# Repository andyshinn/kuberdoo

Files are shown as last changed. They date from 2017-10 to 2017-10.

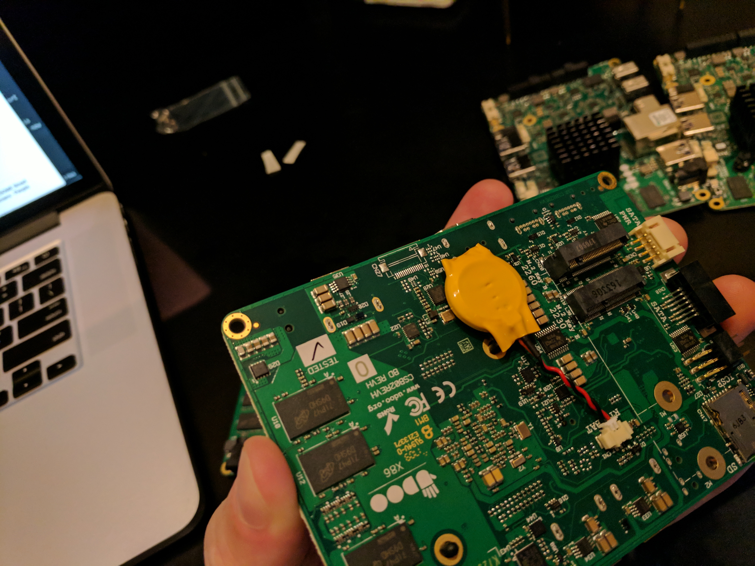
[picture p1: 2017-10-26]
photos/IMG_20171011_182746.jpg

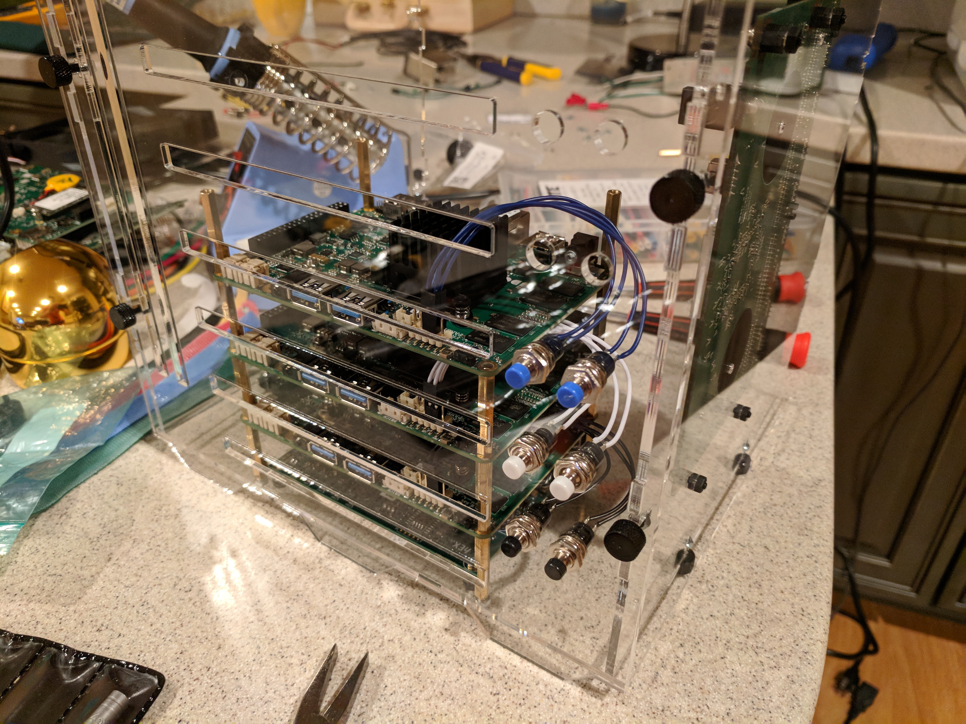
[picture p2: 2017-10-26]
photos/IMG_20171024_211047.jpg

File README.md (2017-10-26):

# About

The Kuberdoo is a not-so-cheap take on a Raspberry Pi cluster. I had originally tested building a small desktop cluster based on the Raspberry Pi but ended up with more compatibility issues than I hoped for. My search for a comparable x86 board started...

There are a couple x86 boards out there. The closest to the UDDO in price and features was the Up Board. Others, such as the Jaguarboard, were lacking in specifications or were not clear if they were even available for purchase (Kickstarter or other). I purchased one UDOO to confirm I could do some things (such as running Docker containers without tweaks and native PXE boot capabilities).

I wanted to build a case around all the components. A friend prototyped an acrylic case that could be laser cut. I immediately started playing with Onshape to take the idea to completion. After learning how to sketch and build the panels, I took the drawings to Pololu for supplying and cutting the acrylic.

## Components

Let's go through some of the main build components and how they came to be. Some of these could be swapped out for different sizes or models. I'll try and point out some of the places where I would have done differently.

### Boards

The main board is the UDOO X86 Advanced.

I did some research on boards. I had originally wanted to go with a Raspberry Pi design. But like most of the other ARM platforms I found in the Pi price range, I just ran into too many limitations for what I wanted to do (the biggest one being lack of proper PXE support). The ARM compatibilities around containers was also frustrating enough that I wanted to go x86_64. Though, I imagine in another year or two, we'll be able to have proper LAN boot options and more transparent multi-architecture support in technologies like Docker.

The UDOO X86 Advanced was the board I settled on. Some of the stuff I wanted to work with (such as Juju) require 4GB of RAM. The Advanced version of the board fit the bill. I imagine two ways to cut costs would be to either go with the Advanced Plus model (which has 32GB eMMC storage built-in) or go with the Basic model and use a cheaper SD card as storage and get only 2GB RAM (in my notes near the bottom I talk about SD storage and why I chose to use a M.2 SSD instead).

### Case

The case is built from laser cut 3mm thick acrylic panels. The CAD is actually public at https://cad.onshape.com/documents/991c4a5831e2f997a4a71842/w/bb91f76a25a96fa561acf156/e/013c2a1a40829f74b89b5690. Anyone can open it up and check out the parts and assembly!

The case was the most fun exercise. I had never used any CAD style tooling before so there was a definite learning curve. But I had some help from a friend who had experience. I stumbled upon Onshape and it felt like a very polished tool. I am actually surprised at how much it is able to do in the browser.

I did not have any calipers (I do now!) for measuring parts at the time. Most of my part and mounting dimensions were from ruler and/or visual only. This led to issues that popped up during assembly:

* The switch mounting holes didn't all line up. Turns out, the mounting holes on the switch PCB are not a perfect rectangle. Oops! I should be able to get the holes aligned better now that I have a pair of calipers.
* The PSU mounting is too far forward. The bottom of the PSU is resting against the front mounting nuts. Not a huge deal but I'll move the PSU back about 5mm so it clears the nuts.
* The notches in the top of the rear panel are not lined up perfectly with the notches in the top panel (off by about 1mm). I was able to use some wire cutters to try the notch in the top panel so it would fit. You can actually see this in the Onshape assembly, I just missed it during my review.
* The bottom panel bears most of the weight yet it only attaches to the sides. This could probably be designed a little better to attach at the front and back as well. Though, being able to screw the top panel into the standoffs help alleviate any pressure by the boards. Not as bad as it sounds (you can't really see it bowing) but it could be better.
* The edges of the case have some flex to them. The notches could have probably been spread out more evenly instead of right next to the bolt holes.
* The front air vents are off by 1.6mm compounding for each vent as I forgot to account for the thickness of the board. Oops again!

The case I built was version `V3`. I went through and tweaked a bunch of constraints for the some of the issues above. If I ever build another case (or if you do, please let me know) I will make a version `V4`.

### Power Supply

The power supply unit (PSU) is a Mean Well RS-100-12. I would later learn that this is an older model and has been replaced by the LRS-100-12. The LRS-100-12 is smaller, has a better efficiency rating (should run cooler), and slightly cheaper. For new builds I'd recommend just using the LRS-100-12.

I looked at dual voltage power supplies (since I was initially thinking I would run a 5v switch and that the fan would be 5v as well). But it turned out to be much bulkier to get the wattage needed at 12 and 5 volts. I also finally found a 12v based switch and realized that most computer fans are actually 12v.

### Networking

The networking components consist of a Netgear GS108 switch, MikroTik hEX router, and some Monoprice SlimRun ethernet cables. The hEX has mechanical drawings available but I couldn't find any for the GS108. Fortunately, it had mounting holes on the board and I was (mostly) able to figure out the correct hole to hole dimensions.

The GS108 was the only switch ii found that was powered by 12 volts (most others were 5 or 9). The hEX has a very wide range input voltage so no worries there. But both the GS108 and hEX are a bit pricey for what they are doing. I think the hEX could be swapped out for the hEX lite and the GS108 for another 12v switch if I searched longer. I am also not fond of the GS108 DC power jack on the back. Had it been on the same side of the ethernet ports I would have been able to move the switch forward a bit more to create some cable space.

The hEX acts not only as a NAT gateway for the internal network but also as a VPN server. To get into the network I create a L2TP VPN connection in my macOS network settings. Once connected, I get access as if I was directly connected to the switch.

I go into the router and VPN configuration specifics later in the installation instructions.

### Fan, Ethernert, C14

The fan is a Antec TwoCool 140mm. The ethernet jack and C13 receptacle were just whatever I found available on Amazon. I'm sure any comparable parts would work as long as the dimensions were tweaked to fit them.

I got the fan in a dual speed model because I wasn't sure how much airflow I needed. So far, the low speed on the fan works well and seems to be keeping everything cool. I haven't measured temperatures yet. But just touching the PSU and heatsinks on the boards feels much cooler than being in the open air.

### Other

There are some other various parts that I already had on hand but I'll try to list them out in case they are needed:

* M3 x 5mm nylon standoffs (brass or metal would be fine as well).
* M3 washers (for spacing the boards off the base panel)
* 18 AWG wire (for building the wiring harness from the PSU to the DC pigtails)
* Various tools (philips screw driver, wire cutters, wire tap crimpers)
* Soldering iron and solder
* Spade terminals for 18 AWG wire (for easy connecting to C14 receptacle. though, you could also just solder the wires on).
* Eye hole terminals for 18 AWG wire to PSU outputs and inputs (though, you could probably just screw the bare wires in if you wanted).
* Shrink tubing in various sizes.
* Double sided foam tape.

## Instructions

Now that you have all the parts, let's get building!

### Router Configuration

Before we install the router we need to do some pre-configuration so we can connect to it.

1. Connect up your computer to the second ethernet port and make sure it is configured for DHCP.
1. Power up the hEX with the included power adapter.
1. SSH or telnet to 192.168.88.1.
1. Copy and paste the configuration from https://github.com/andyshinn/kuberdoo/blob/master/config/default_vpn.rsc (this should get the NAT, firewall, VPN, and basics set up).

After loading the configuration, connect port 1 up to your home network, power cycle the hEX, and verify that you can connect to it (you will need to consult your home router to find out what address the MikroTik was given). For example, my home network is 10.0.1.0/24 and the MikroTik got an address of 10.0.1.58. I am able to connect to the device via SSH at 10.0.1.58 with user `admin` and password `kub3rd00`. There is also a web interface at http://10.0.1.58/ if you prefer to configure the device that way.

Now that we have verified the device can be remotely connected to, it is ready to be installed into the case. You can leave the router powered up because we'll use the TFTP server configured on it to bootstrap the first UDOO board next.

### UDOO Preparation

In addition to the router, we need to prep the UDOO boards so that they properly boot from PXE and failover to hard drive when no PXE server is available. We also need to install Ubuntu on one of the boards so that we have a node to bootstrap from.

1. Install the M.2 SSDs onto all the boards. The UDOO X86 should have come with a small bag of M.2 mounting hardware.
1. Use a small piece of double sided foam tape to hold down the CMOS battery.
1. Connect up a UDOO to monitor via HDMI or mini DisplayPort, keyboard, and a 12 volt DC power adapter. You can use the one that comes with the Netgear GS108 switch. But don't use the adapter that comes with the MikroTik hEX as it is 24 volts!
1. Start repeatedly pressing the <kbd>ESC</kbd> key on the keyboard while applying power to the UDOO board.
1. Enter the SCU once at the setup screen.
1. Navigate to _Power_ and set the _Power Fail Resume Type_ to _Always OFF_ (we don't want to boards automatically powering on).
1. Navigate to _Boot_ menu.
1. Set _Boot Type_ to _Legacy_ (UEFI doesn't failover to hard disk properly when PXE fails).
1. Enable _PXE boot to LAN_.
1. Navigate to _Exit_ and choose _Exit Saving Changes_.
1. Keep pressing the ESC key as the device reboots again.
1. Navigate to the _Boot_ menu again and there should be a new _Legacy_ menu.
1. Under _Legacy_ submenu navigate to _Boot Type Order_.
1. Highlight _Hard Disk Drive_ and use the <kbd>-</kbd> key to move it under _Other_ (so that PXE will boot before the SSD).
1. Navigate to _Exit_ and choose _Exit Saving Changes_.

Repeat these steps for all the boards. It is difficult to hook up HDMI and keyboard to the boards while they are in the case so this is why we do it now. We want the boards to boot and install headless.

Choose one of the boards to be the head node. This is the board we'll use to install Ubuntu onto and will run Ubuntu MAAS or other PXE server to bootstrap the other boards. With this board:

1. Connect the board up to your monitor and keyboard again.
1. Connect this board to one of the ethernet ports on the MikroTik hEX.
1. Power on the board and it should PXE boot into https://netboot.xyz/ from the TFTP server we previously set up on the hEX.
1. Navigate the menus to install Ubuntu 16.04 or other flavor of Linux (if you plan to use something other than MAAS).
1. Follow through the installation and verify you can SSH to the node afterwards.

Once we can remotely connect to this node it is safe to go in the case. We know that we can connect to it without needing monitor and keyboard. It may be helpful to number the boards at this point. I put a number 1 on my head node CMOS battery and labeled the others boards 2 through 6.

### Wiring Harness

I started by mocking up the boards on the bottom panel and the PSU on the side panel. This helped give an idea of how long the DC plug pigtails needed to be for the wiring harness. I ended up making two, one harness for the 6 boards and one for the fan, switch, and router. The harnesses are the pigtails soldered to 18 AWG wire leads that plug into the positive and negative terminals on the PSU.

### Mounting Switch

### Mounting Router

### Head Node MAAS

```
sudo apt install maas
sudo maas createadmin
```

## Notes

### Storage

The UDOO X86 supports SD card, SATA, and M.2 type SSD. It also has a model that has a built-in 32GB eMMC option.

I tested using a SD card (Samsung 32GB EVO Select U1) and it was too slow for my liking. Definitely the cheaper of the options available (only $13 on Amazon at the time). If speed isn't your primary concern then this would be an option to keep cost down. It would be worth looking at the Samsung 64GB EVO Select U3 or other U3 SD cards as they should be faster than the U1.

I picked up the lowest cost 64GB M.2 SSD I could get on Amazon. It turned out to be magnitudes faster than the SD card. In comparison, it took 20+ minutes to install Ubuntu onto the Samsung 32GB EVO and only about 5 minutes onto the M.S SSD.

You might look at the 1.8 inch SATA SSD available if space and cabling is less of a concern. With these you'd likely get more performance and space per dollar. I won't need more than 64GB per node and didn't want to deal with the extra parts and cabling.

I figured if the SD card was this slow then a USB key wouldn't be much faster so I didn't test this option. But a faster USB drive could be an option if space and cabling isn't a concern.

### Network

One of my goals was to have an isolated network for protocols like PXE, DHCP, and DNS. This should allow use of the cluster for testing that might conflict with the parent network. I also needed something that would act as a VPN server as it would be my way into the network.

I had looked at some smaller home routers and boards to run pfSense. But none of them fit well (not enough ports, too big, more expensive than home routers). I then stumbled upon Mikrotik (which I had known about for many years). The [hEX](https://mikrotik.com/product/RB750Gr3) (and [hEX lite](https://mikrotik.com/product/RB750r2)) were pretty much a perfect fit. I was able to prototype everything the router needed to do in VirtualBox thanks to the Mikrotik x86 distribution.

The next model up (RB2011iL-IN) had 8 ports but not all were gigabit. I think if there were an 8 port version of the hEX or hEX lite at $99 that would have been the better buy rather than a hEX and dumb switch. Even the bare RouterBOARD with more than 1 port ([the RB450](https://mikrotik.com/product/RB450)) costs more than the hEX.

Another thought was to use the [hAP](https://mikrotik.com/product/RB951Ui-2nD) and do wireless client to the parent network. This would remove the need for a wired cable uplink. Though, you'd need to change the wireless client settings anytime it moved to a new wireless network.

### Other

Some other thoughts on other physical cluster stuff I'd love to replicate on the desktop:

* Bonding and port failover. Mikrotik handles this. But we'd need boards that had multiple interfaces (UP squared might be a good candidate for this).
* VLANs and routing between them. Mikrotik already supports this. Would t least need a switch that could also handle VLANs and tagging / trunking.
* IPMI / OOB management. The onboard Arduino has the ability to power on/off the main board. I wonder if it could act as a simple IPMI device?
* HDMI / USB case ports for each board. It should be possible to widen the case and make room for some HDMI and USB passthrough cables for each board. This would make it easier to service (changing BIOS options, debugging broken boot, etc.)

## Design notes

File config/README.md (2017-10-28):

# Config Files

## embed.ipxe

The `embed.ipxe` file is used to build the iPXE `undionly.kpxe` binary with the `embed.ipxe` embedded inside. This PXE booter will chainload to `tftp://192.168.88.1/preseed.ipxe`. This makes it easier for us to make edits to the iPXE script without having to rebuild the iPXE binary. See http://ipxe.org/embed for information on building the binary with the embedded script.

## preseed.cfg

This is the main Ubuntu preseed file. It automates the installation of Ubuntu for us so we don't need a keyboard or monitor. This gets passed to the `url` parameter as a kernel command line option at boot. See the `preseed.ipxe` script for the command line that gets passed.

## preseed.ipxe

This is the chainloaded iPXE script. We use this to pull down a remote Ubuntu installer image and boot using our `preseed.cfg` file. The installation procdes automatically and shuts down the node when done (so we can disable the TFTP options before we next power on).

## preseed.kpxe

This is the `undionly.kpxe` file with our embedded `embed.ipxe` script. It was generated using instructions at http://ipxe.org/embed and then renamed from `undionly.kpxe` to `preseed.kpxe`.

## ros_default.rsc

This is the default configuration of the MikroTik hEX before any of our edits. It is just here for reference.

## ros_kuberdoo.rsc

This is the MikroTik hEX configuration with our edits. It can be applied on top of the default MikroTik configuration. You will likely want to change the DHCP lease MAC addresses of the boards and the global password at top (which is used for VPN and admin functions).

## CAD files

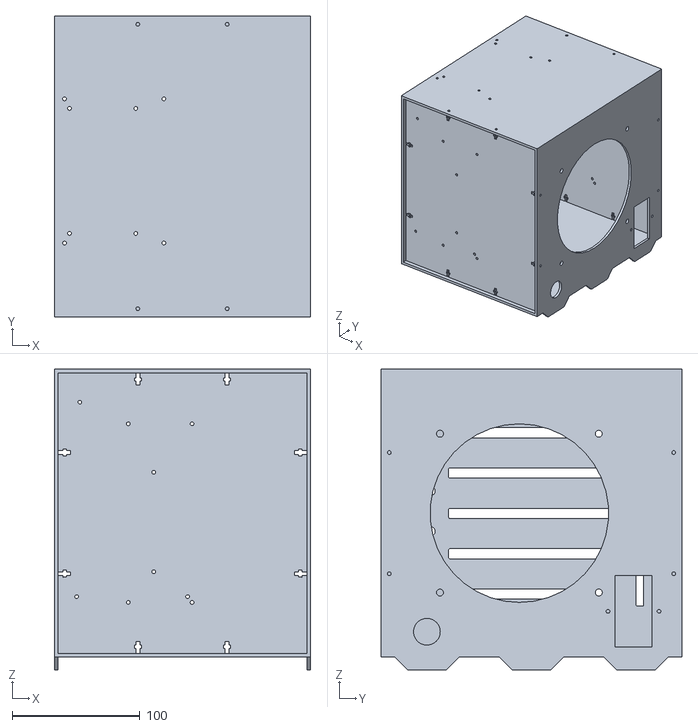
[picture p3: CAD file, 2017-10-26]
drawings/kuberdoo-assembled.stl
201.0 x 236.0 x 236.0

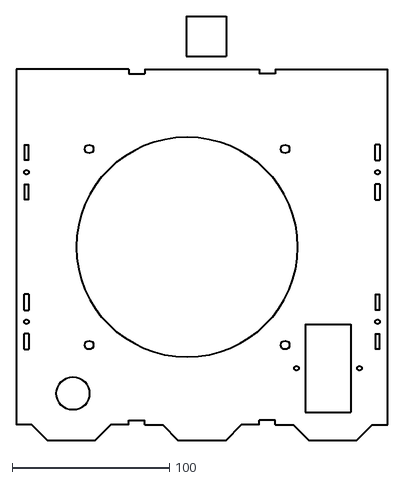
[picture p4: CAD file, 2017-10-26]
drawings/v3/kuberdoo-back-panel-v3.dxf
236.0 x 269.5

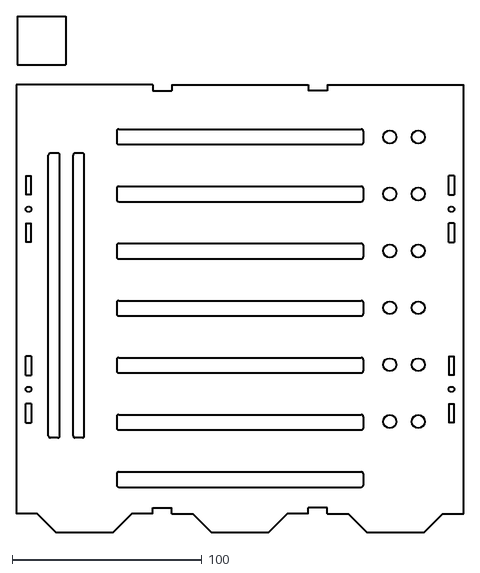
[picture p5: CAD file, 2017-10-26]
drawings/v3/kuberdoo-front-panel-v3.dxf
236.0 x 272.1

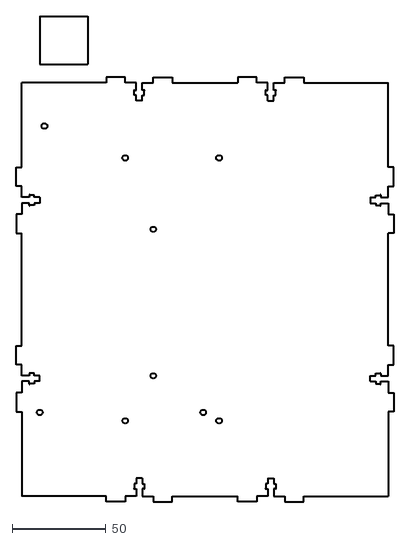
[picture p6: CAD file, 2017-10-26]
drawings/v3/kuberdoo-side-panels-v3.dxf
201.0 x 258.4

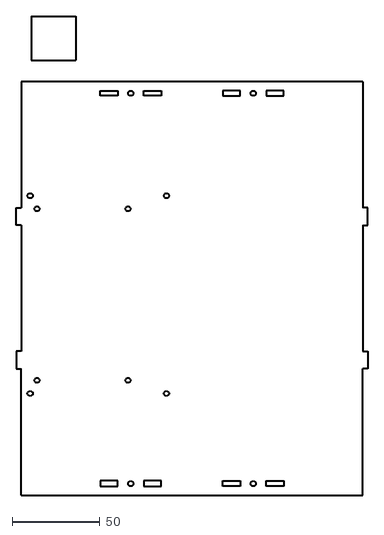
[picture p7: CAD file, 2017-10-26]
drawings/v3/kuberdoo-top-bottom-panel-v3.dxf
201.0 x 273.7

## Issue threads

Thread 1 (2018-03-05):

MAAS config

zarez, 2018-03-05:
Hi Andy,

I tried to install and configure maas to node provisioning without much success. I did set next-server on hex to  maas node(192.168.33.11) . Set maas with forwarding DNS to router. Looks like have to open the kuber to see whats posting on boot. Any tips are appreciated.

Cheers,
Gjorgji

zarez, 2018-03-05:
Found the issue: set boot-file-name=pxelinux.0( it was netboot.xyz.kpxe)
Now maas has the node but I cannot not commission due to power configuration. what did you pick up for power type?

zarez, 2018-03-05:
Set to manual. Now its commissioned and in Ready state. Will play more tomorrow.

andyshinn, 2018-03-05:
Yep, setting to manual is the correct way for these boards. When I was using MAAS it looks something like this:

* Commision node
* Hit power button
* Wait for power light to go back to yellow
* Provision node
* Hit power button

The config in this repository for the MikroTik probably doesn't have MAAS as the default. I had a couple different options to do preseed Ubuntu or netboot.xyz. I would switch between them doing something like:

```
/ip dhcp-server lease> set [ find dhcp-option ~ "udoo*" ] dhcp-option-set=boot-preseed
```

Then when they are done booting I would turn off PXE boot with:

```
/ip dhcp-server lease set [ find dhcp-option ~ "udoo*" ] dhcp-option-set=none
```

Hope that helps!

zarez, 2018-03-07:
I just changed the next-server to maas IP and the boot-file-name to pxelinux.0. Deployed the nodes from maas. The only problem was hostnames as for some reason maas was using some of his own, not the one from dhcp(hex).
What deployment did you use for kubernetes?

andyshinn, 2018-03-07:
MAAS will always generate a hostname. You need to click on the hostname to edit it after it shows up in MAAS (you can edit is before comissioning). After that, it will stay tied to that MAC address in MAAS.

I used Kubespray (https://github.com/kubernetes-incubator/kubespray) to build my Kubernetes cluster. I think it is the easiest to use for own hardware. My inventory file looked something like this (change your IP to match if using different subnet):

```
udoo1 ansible_host=192.168.88.11
udoo2 ansible_host=192.168.88.12
udoo3 ansible_host=192.168.88.13
udoo4 ansible_host=192.168.88.14
udoo5 ansible_host=192.168.88.15
udoo6 ansible_host=192.168.88.16

[kube-master]
udoo1
udoo2

[etcd]
udoo1
udoo2
udoo3

[kube-node]
udoo1
udoo2
udoo3
udoo4
udoo5
udoo6

[k8s-cluster:children]
kube-node
kube-master
```

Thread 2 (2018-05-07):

Thank you + a quick question

tkellen, 2018-05-07:
First, thank you for sharing this project, it's awesome :dancer:

I am about to attempt a build of my own. The README for this project mentions you have updated CAD files... and it looks like you made an update at OnShape over the weekend? Is that the v4 model you mentioned? If not, would you be willing to share? I'd love to give it a shot and would be more than happy to share photos/a report of how it went.

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

Cheers!

tkellen, 2018-05-07:
Neat, thanks so much for the reply @andyshinn. I'll hang tight.

One additional thought just occurred to me. In your README you recommend a newer PSU, (which I did order). Here's the spec sheet on it:
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.

Not suggesting you need to update it for me, but that seems like an easy wrinkle to miss if you don't specify which the V4 is designed for.

Also, as a total aside, if you email me your address (tyler@sleekcode.net) I'll order two cases and send the second your way!

andyshinn, 2018-05-07:
Ah, you are correct. The mounting is different than the RS-100. But it shouldn't be too difficult to change. I should be able to change it for that hole mounting when I take a look at it.

Also, there is something else about the PSU that I just remembered. The depth holes is rated for 2mm and I think I have 6mm thumb screws on the list of parts for mounting this. The 3mm thickness of the case means that the screws are technically too long for the PSU mounting. Though, I am using 6mm in mine and it seems to be fine (doesn't seem to be hitting anything on the PSU board but I'm guessing the mac depth is so that it doesn't come in contact with the circuit board).

andyshinn, 2018-05-08:
I made the edits and tagged it as V4 version in OnShape. I also fixed an erroneous deletion of the assembly panel tab as well (so you can view the assembled case again).

Take a look and let me know if anything looks strange. I looked it over briefly but I think it looks good. The edits were pretty minor. I've just added two holes for the LRS-100 so either could be used. It should sit in the same position from the bottom terminal edge of the PSU.

Also, I may be wrong on the screw depth for the LRS-100. The drawing actually says L=4.5 (I'm guessing this is the thread depth) so deeper than I thought!

tkellen, 2018-05-08:
I haven't touched a CAD program in... I guess about 6 years?
https://github.com/tkellen/super-portable-alumium-oven

To my untrained eye, this looks good @andyshinn. Thank you so much!

I'm going to upload these to pololu this afternoon. Say, you didn't reply RE: my having a second case made and sending it your way. Would you like me to do that or no?

zarez, 2018-05-08:
One note: C14 power connector. Depends on where you source it, you might have to sand the case opening a bit. Dont ask me how I know.

andyshinn, 2018-05-08:
Thanks for the info zarez.

Thanks for the case offer. But no need to send me one :)

zarez, 2018-05-10:
I was thinking adding some ssd that I have laying around, but found that the port is blocked by psu. I guess I can get the boards upside down but have no time to take apart now ( I am actually using this puppy alot)

zarez, 2018-05-10:
@andyshinn I was actually thinking about asking UDOO guys if they are interested in making strip down version of the board for this kind of usage. I think will little bit of code you can make you onw mini cloud

andyshinn, 2018-05-10:
Cool. If you have some suggestions for a next generation version of the case I would start a new issue instead of adding to this one. Let's keep this issue specific to the V4 case cutout.

If you checkout the UDDO forums there is a case section and there are some other mini cloud ideas there as well. Their stripped down boards are all ARM based at the moment. If I had to guess, it is likely that the Atom processor architecture is what limits what they can strip out of the x86 board.

tkellen, 2018-05-11:
Most of the parts arrived today! I'm heading out for the evening but I wanted to post a quick update for anyone thinking of ordering the v4. Hold off a bit.

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

Haven't put my head to what happened yet, but unless I've assembled something wrong,
I think the vent spacing for the boards needs another pass. Good call not ordering two @andyshinn :smile:

More this weekend when I can look more closely!

tkellen, 2018-05-12:
Back again! So, the vent spacing is perfect now, but the top six vents need to come down ~11mm. Unfortunately the battery in my calipers is dead, but here's a shot showing that:
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

The bottom vent needs to remain where it is, be moved down about half that distance, or be removed. Also, I think it would be ideal if the power/reset switches were centered vertically with the vents.

I am going to sign up for OnShape now and try to sort out how to make these adjustments and share them back.

Other wrinkles:

1. The PSU hole spacing doesn't appear to be correct for the LRS-100 (photo of this to follow later).
2. The C14 receptacle cutout needs to be about 1mm taller.

Anything you'd like to see that I haven't mentioned @andyshinn?

tkellen, 2018-05-13:
Not quite sure how to share these back with you @andyshinn, but, I reduced the vent count to 6, set the constraint for distance of first vent to 31.6 from the bottom and adjusted the distance for the power/reset switches to start at 35.1 so they would be centered.

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

The holes for the PSU turned out to be fine and a bit of shaving with my pocket knife got the C14 receptacle in place.

I'm curious to hear your thoughts about skipping a vent for the router? Seems like there will be plenty of airflow with this 140mm fan and all the other vents...

tkellen, 2018-05-13:
...also extended the side vents to start and stop with the main vents. Here's a link:

https://cad.onshape.com/documents/8ba54d73704d0bbd7765ead9/v/0d3974aec15f72b5fb83378f/e/0956c2e4007c3a72cca42eb4

I am slowly backing away from this CAD program now. I can see myself blowing huge amounts of time in here tinkering :p

andyshinn, 2018-05-14:
That OnShape document doesn't seem to be public (I can't open it).

I guess the switches could be aligned with the vents. They were originally but I left them in place when I fixed the alignment with the heatsinks.

What is the reasoning for removing the vent for the router?

tkellen, 2018-05-14:
Whoops! Just made the document public. Reason for removing the router vent is based on a silly desire for the vent spacing to be symmetrical throughout and a belief (I am hoping you can validate) that it probably isn't needed.

andyshinn, 2018-05-18:
There is actually a OnShape feature to make different configurations for a document. I'll probably use this feature to make configurations for the different power supplies and vent layouts. It should also make it easier to add different configurations later on for different parts / part sizes.

hfoakley1948, 2018-06-03:
My parts have arrived and I would like to order a case at Pololu. Is there a v4 at OnShape or a
version available at Pololu that I could reference for an order? Great project.

andyshinn, 2018-06-04:
I did end up tagging a v4 version at OnShape you can reference (you may need to login to OnShape to see all the versions). But I can't remember if there were problems in the latest version.

@tkellen can you confirm if there were some changes that should be made / stuff not lining up correctly? From your previous message it sounded like maybe you had figured out everything and there were not any changes needed.

tkellen, 2018-06-04:
@andyshinn, the correct spacing to the bottom of the first udoo board is shown here:
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

(note that this drawing omits the vent for the router). All the other changes I mentioned are not strictly necessary.

tkellen, 2018-06-04:
Also, just to confirm, https://cad.onshape.com/documents/8ba54d73704d0bbd7765ead9/v/0d3974aec15f72b5fb83378f/e/0956c2e4007c3a72cca42eb4 is exactly the same as your v4 with the exception to the changes I made for vent spacing and power switch alignment (which I can confirm worked out as planned). I think it would make sense to replace your front panel with the one from this project and call it v5 or some such.

andyshinn, 2018-06-05:
Wouldn't that make the vents start at the bottom of the board? My original intent was for the vents to align above the board so that air flowed over the top of it and directly over the heatsink.

Also, I'm not quite sure why we need to omit vent for the router. Is that just because in this new configuration there isn't enough spacing for it?

@hfoakley1948 in either case, the v4 version should work. Any changes we make for a v5 version would be vent spacing / removal of the vent for the router. If those are not a concern then you could take the drawings for v4 now and send them to Pololu. I'm not sure if Pololu has a way to reference previous cuts.

tkellen, 2018-06-11:
Sorry for the slow reply @andyshinn, I've been out of town / offline. I see what you mean now! I have the vents lined up with the bottom of the board so I can use the ports. I think doubling their height might serve both purposes? RE: omitting the vent for the router, that was based on desire for the vents to be evenly spaced across the entire front panel and a belief there would be enough airflow without it (so far an accurate one).

andyshinn, 2018-06-11:
I see. I might play around with that. The original intent was only for airflow and not port access. The original spacing did line up with the top board ports but that was only by accident.

The slots could serve both purposes if they were maybe slightly wider and aligned at the bottom of the board.

ritchington, 2019-05-04:
Hey Friends!

So in the spirit of ruining everything (I don't know how to use Onshape), I put Tkellen's v5 into Tinkercad and made some edits, then exported to SVG. I built this last year, but my cat knocked it off a shelf and broke the case, so I've decided to recut the case with some improvements...

- Nearly Doubled the front slot height, for access to USB Ports, and above board cooling
- Removed the front Vertical Ventilation slots (You'll see why in a second)
- Modified Side holes to mount TWO POWER SUPPLIES (LRS-75-5 + LRS-100-12) and still fit
- Removed otherwise superfluous holes
- Made the back power supply hole just the teeniest bit deeper
- Increased the size of the ethernet cable hole (I bought a mount that was bigger than original I think)
- Added Power Supply venting holes to the bottom and top
- Created a Tray piece, that mounts on the UdooX86 holes, with holes for Raspberry PI B, Odroid Xu4, and 2.5inch HDD/SSD

I'm too poor to buy 6 Udoo X86's, so now I can use it as a prototyping/homelab for a whole heap of things. 5V can now power PIs, Odroid, HDD, and any other crap you wanna put in there.

Files attached here :)
Enjoy!

[Kuberdoo Ritchington v6.zip](https://github.com/andyshinn/kuberdoo/files/3144497/Kuberdoo.Ritchington.v6.zip)

Closed 2019-07-28.

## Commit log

2017-10-26 initial information and drawings
    [kuberdoo-assembled.stl, kuberdoo-back-panel-v3.dxf, kuberdoo-front-panel-v3.dxf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]
2017-10-28 PXE boot config files
    [preseed.cfg]
